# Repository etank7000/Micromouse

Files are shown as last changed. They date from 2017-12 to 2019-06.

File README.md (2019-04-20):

# Micromouse
UCLA IEEE Micromouse 2017-2018

To get the arm toolchain used in this repo, check out the following link and download the appropriate tar file. Be sure to read the included readme in the tar file as well.

https://developer.arm.com/open-source/gnu-toolchain/gnu-rm/downloads/7-2017-q4-major-1-1

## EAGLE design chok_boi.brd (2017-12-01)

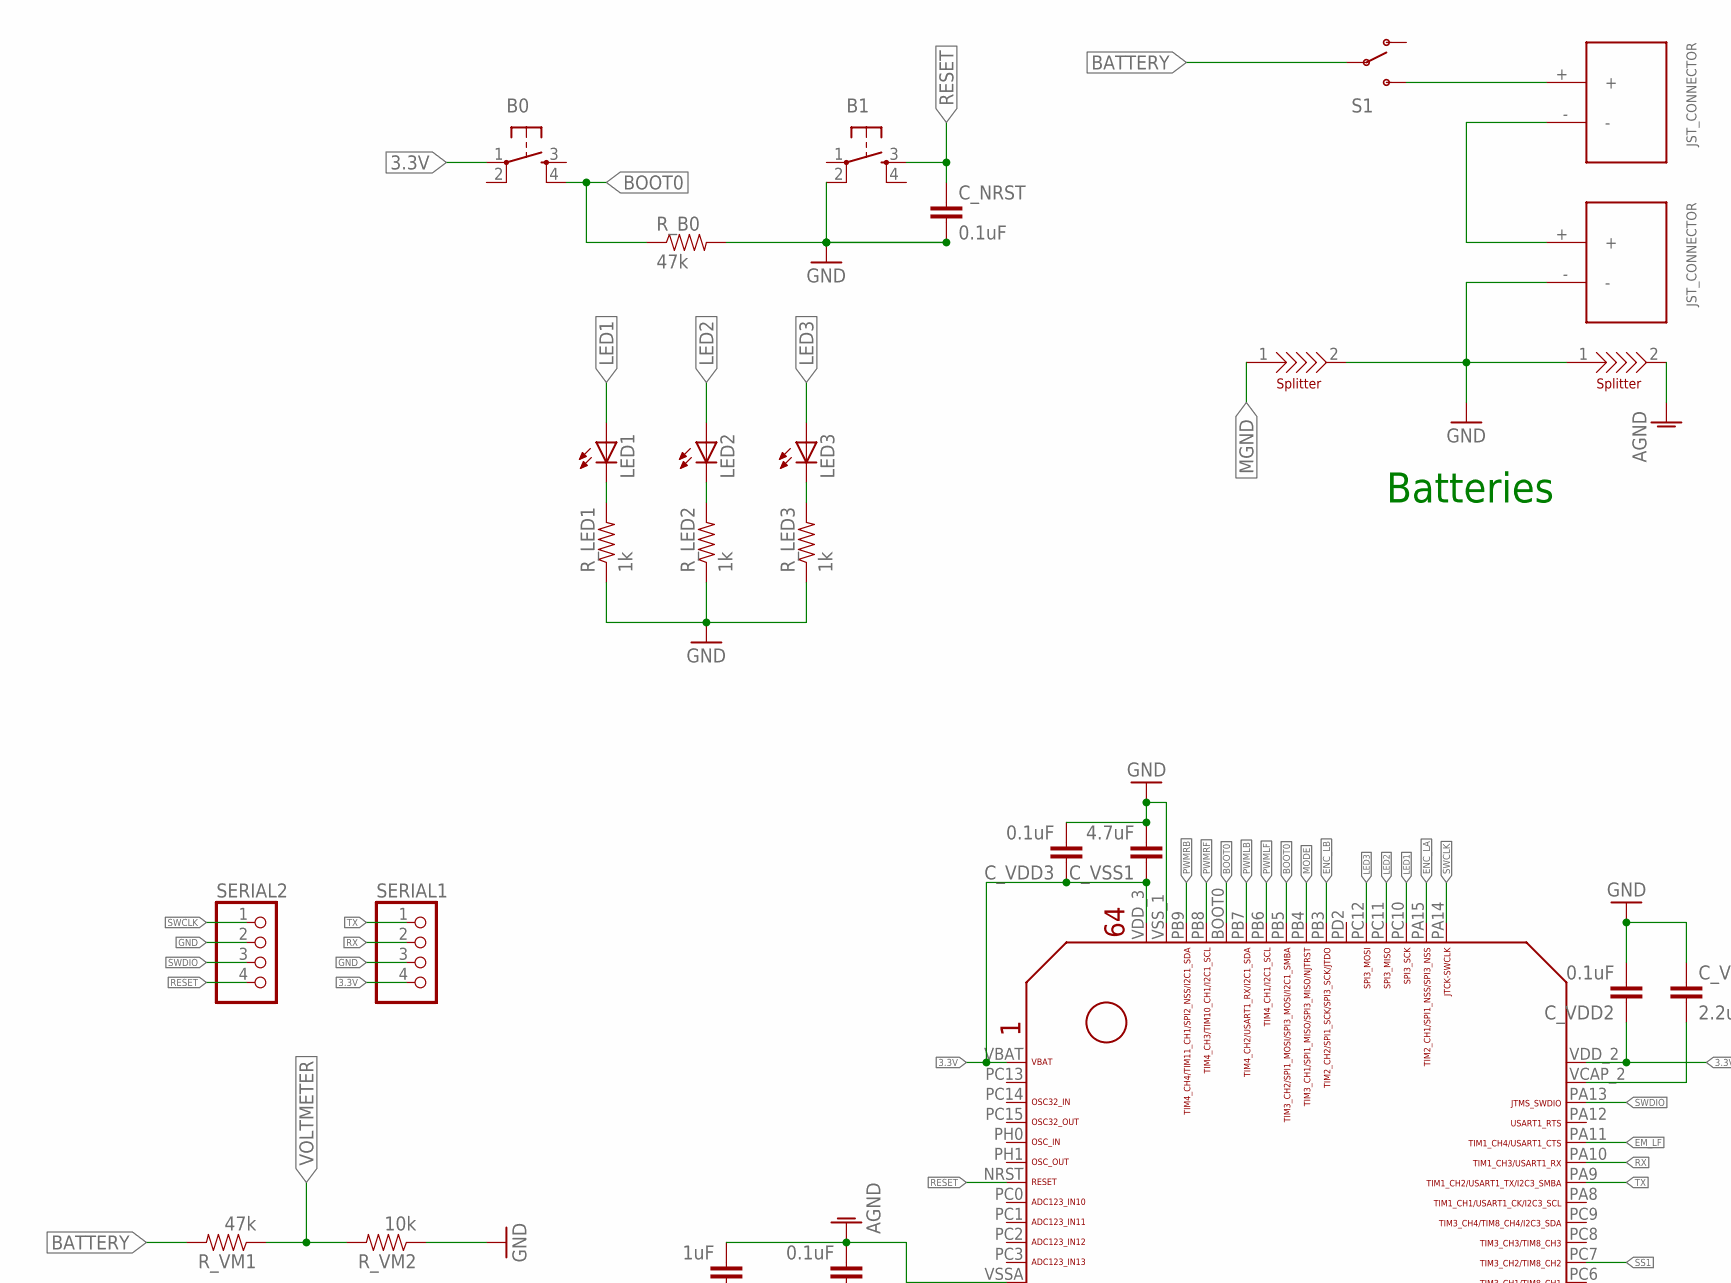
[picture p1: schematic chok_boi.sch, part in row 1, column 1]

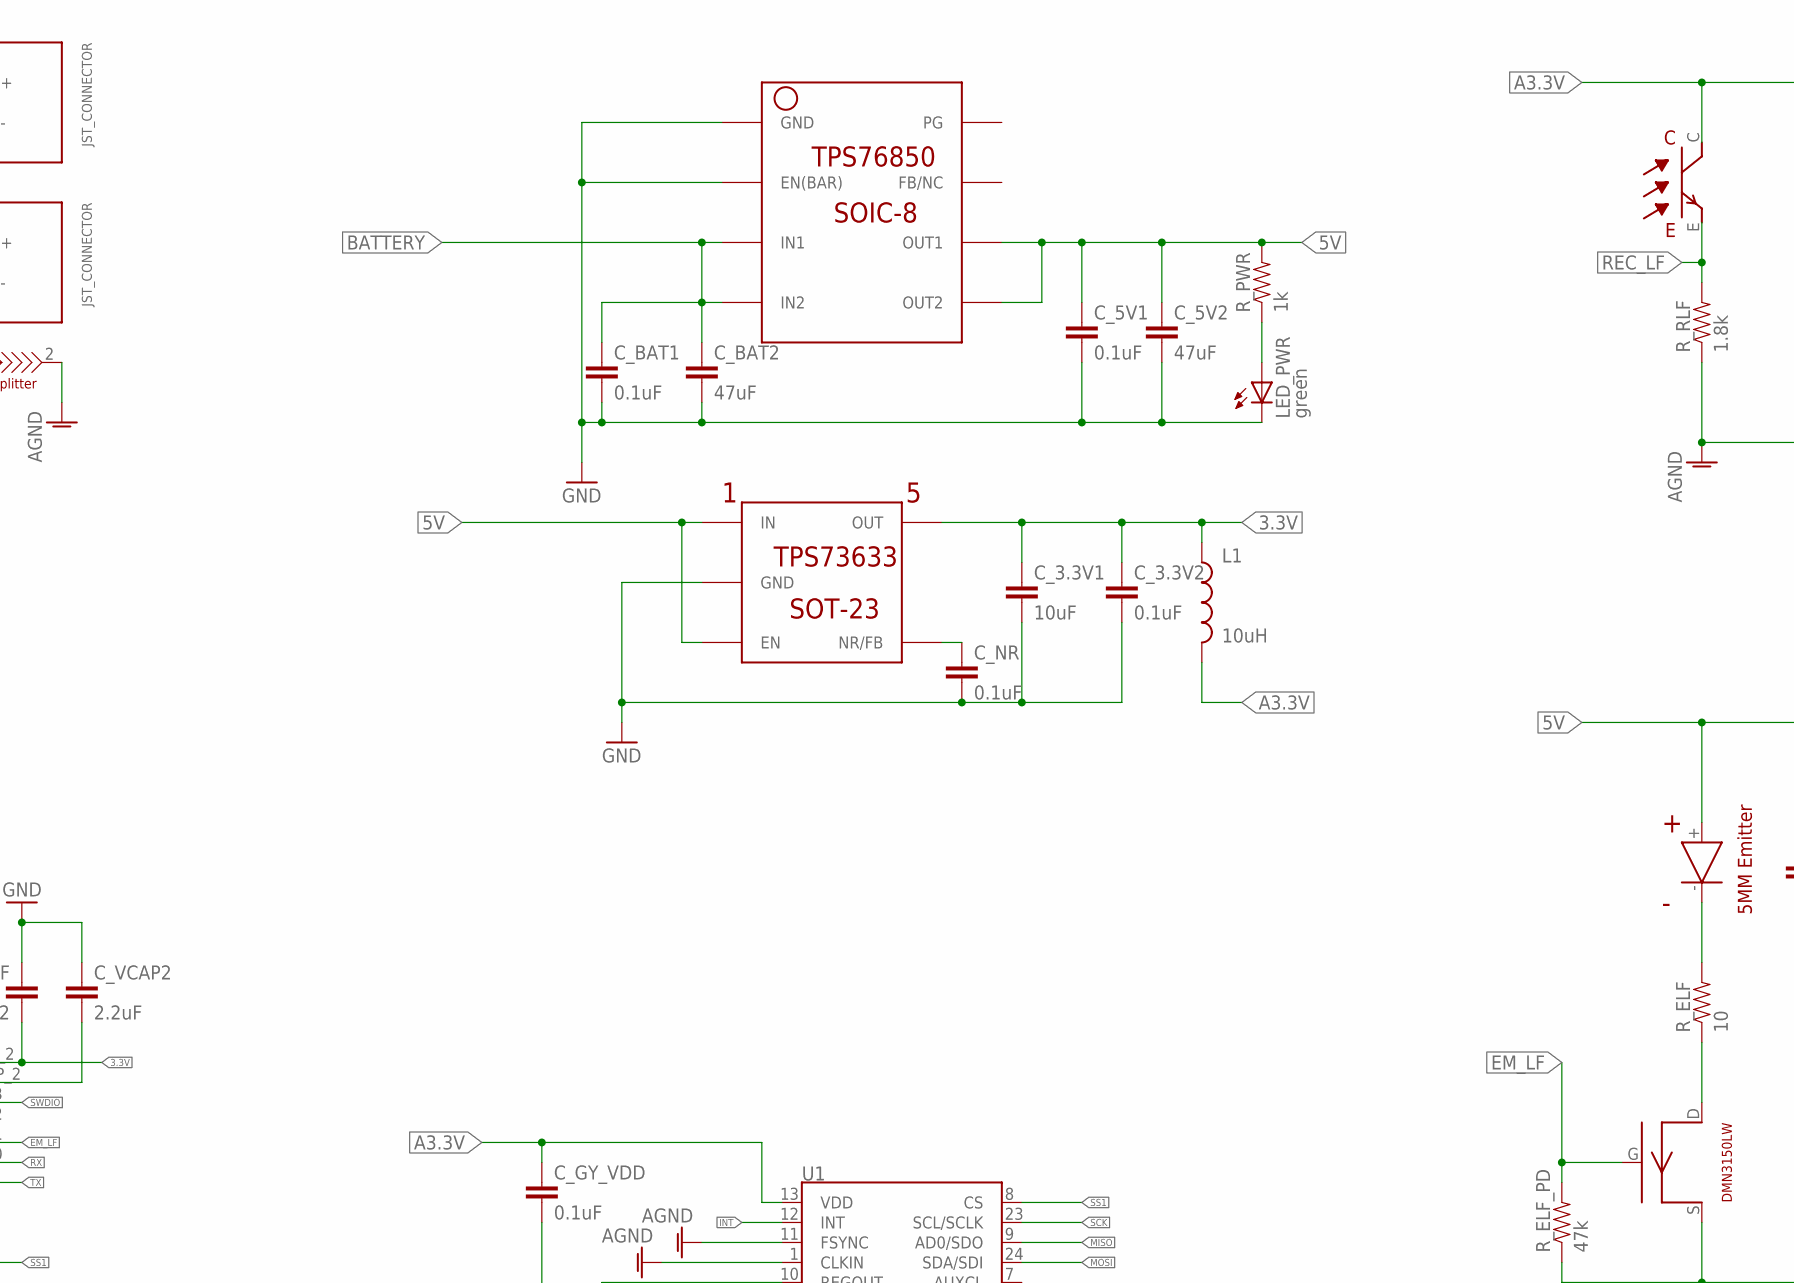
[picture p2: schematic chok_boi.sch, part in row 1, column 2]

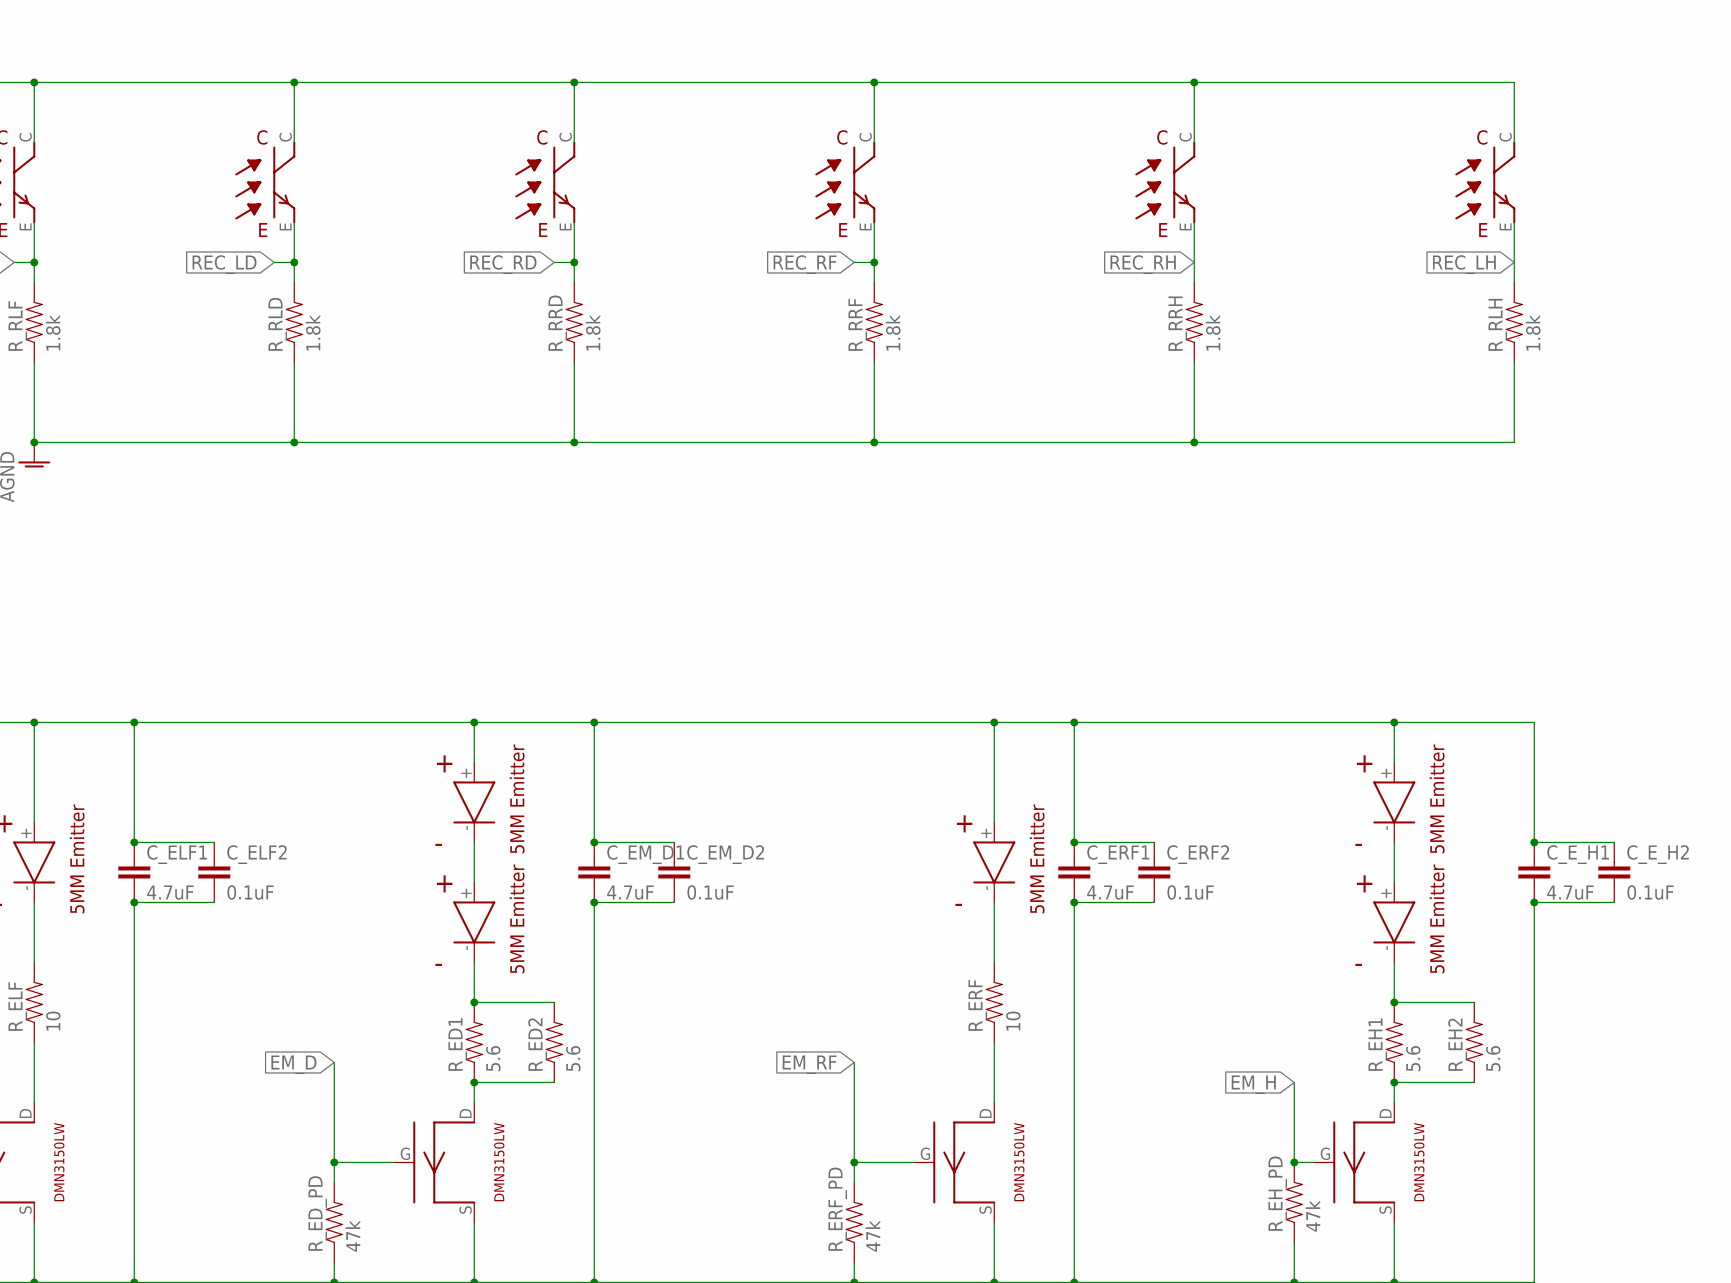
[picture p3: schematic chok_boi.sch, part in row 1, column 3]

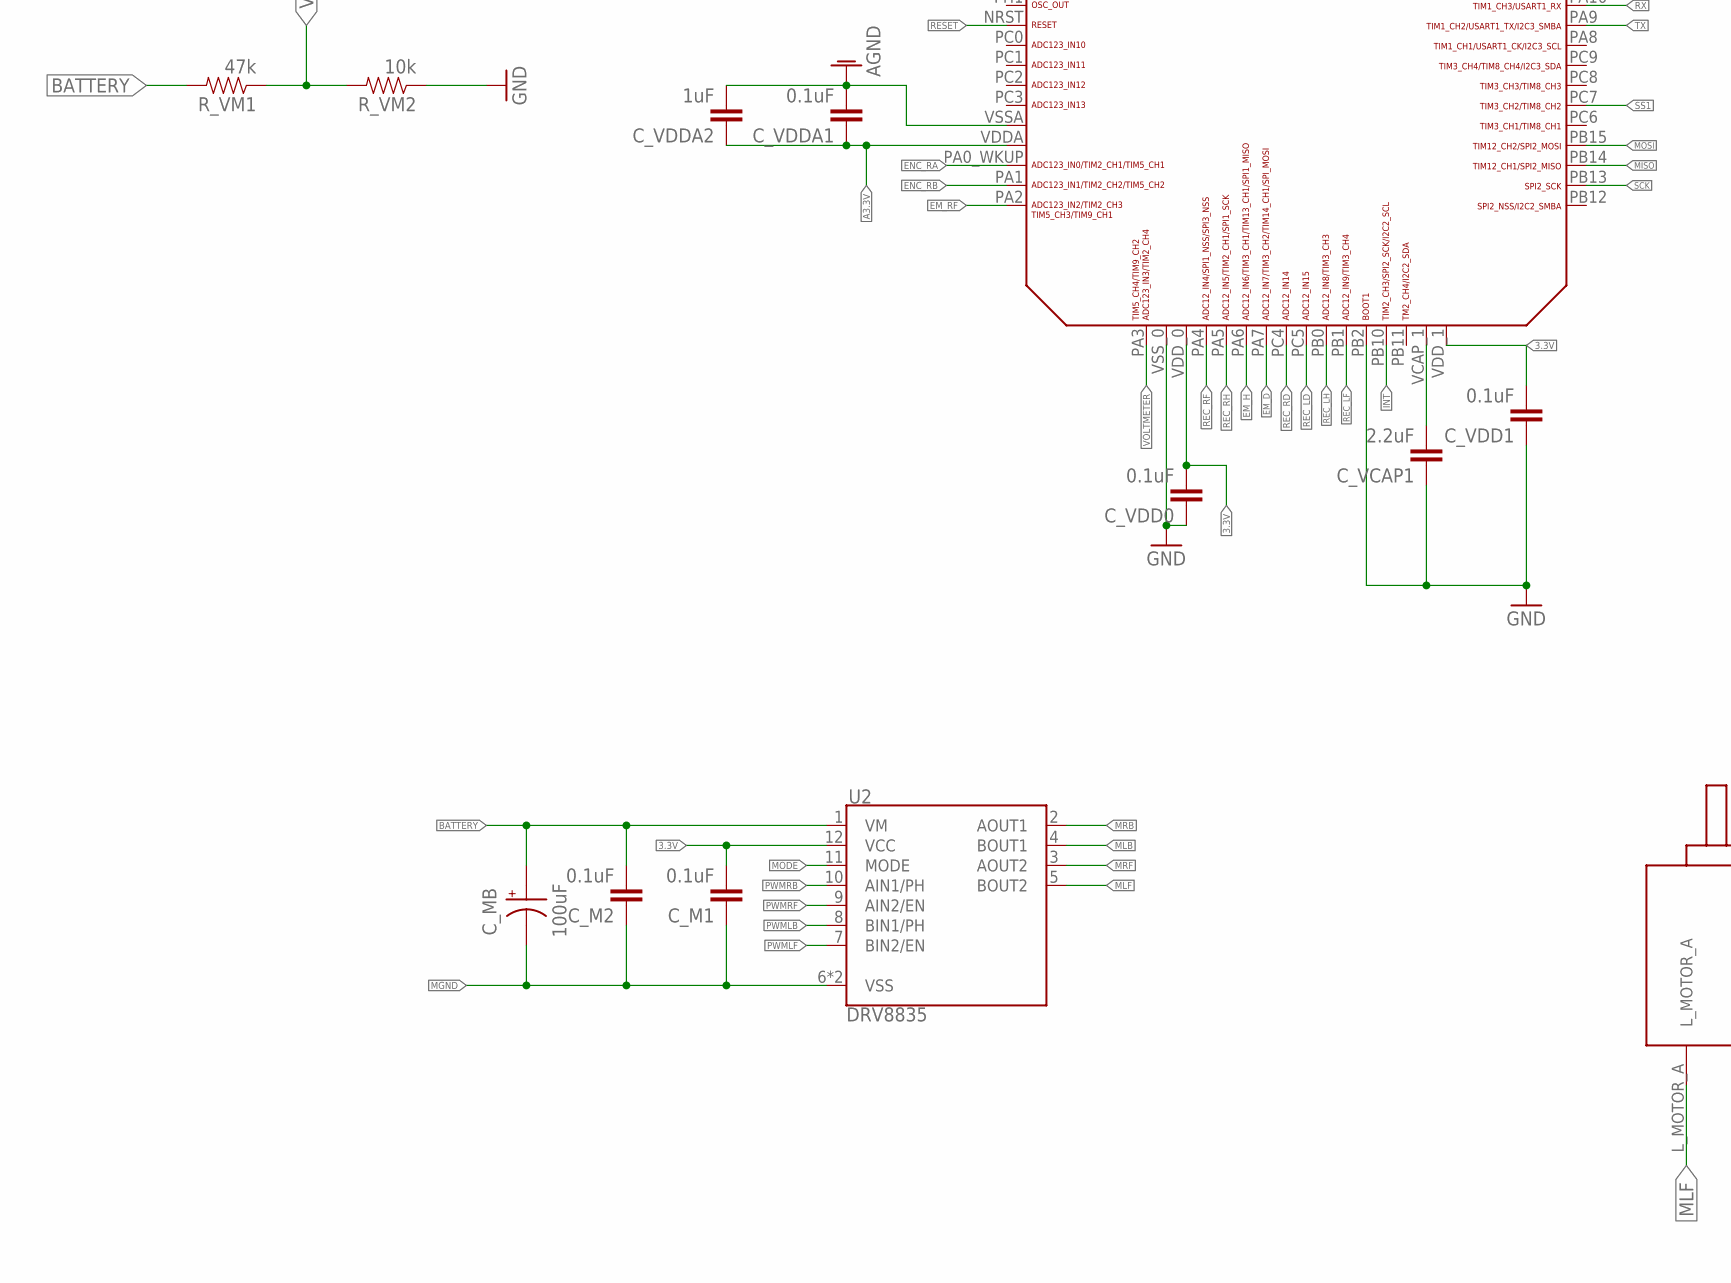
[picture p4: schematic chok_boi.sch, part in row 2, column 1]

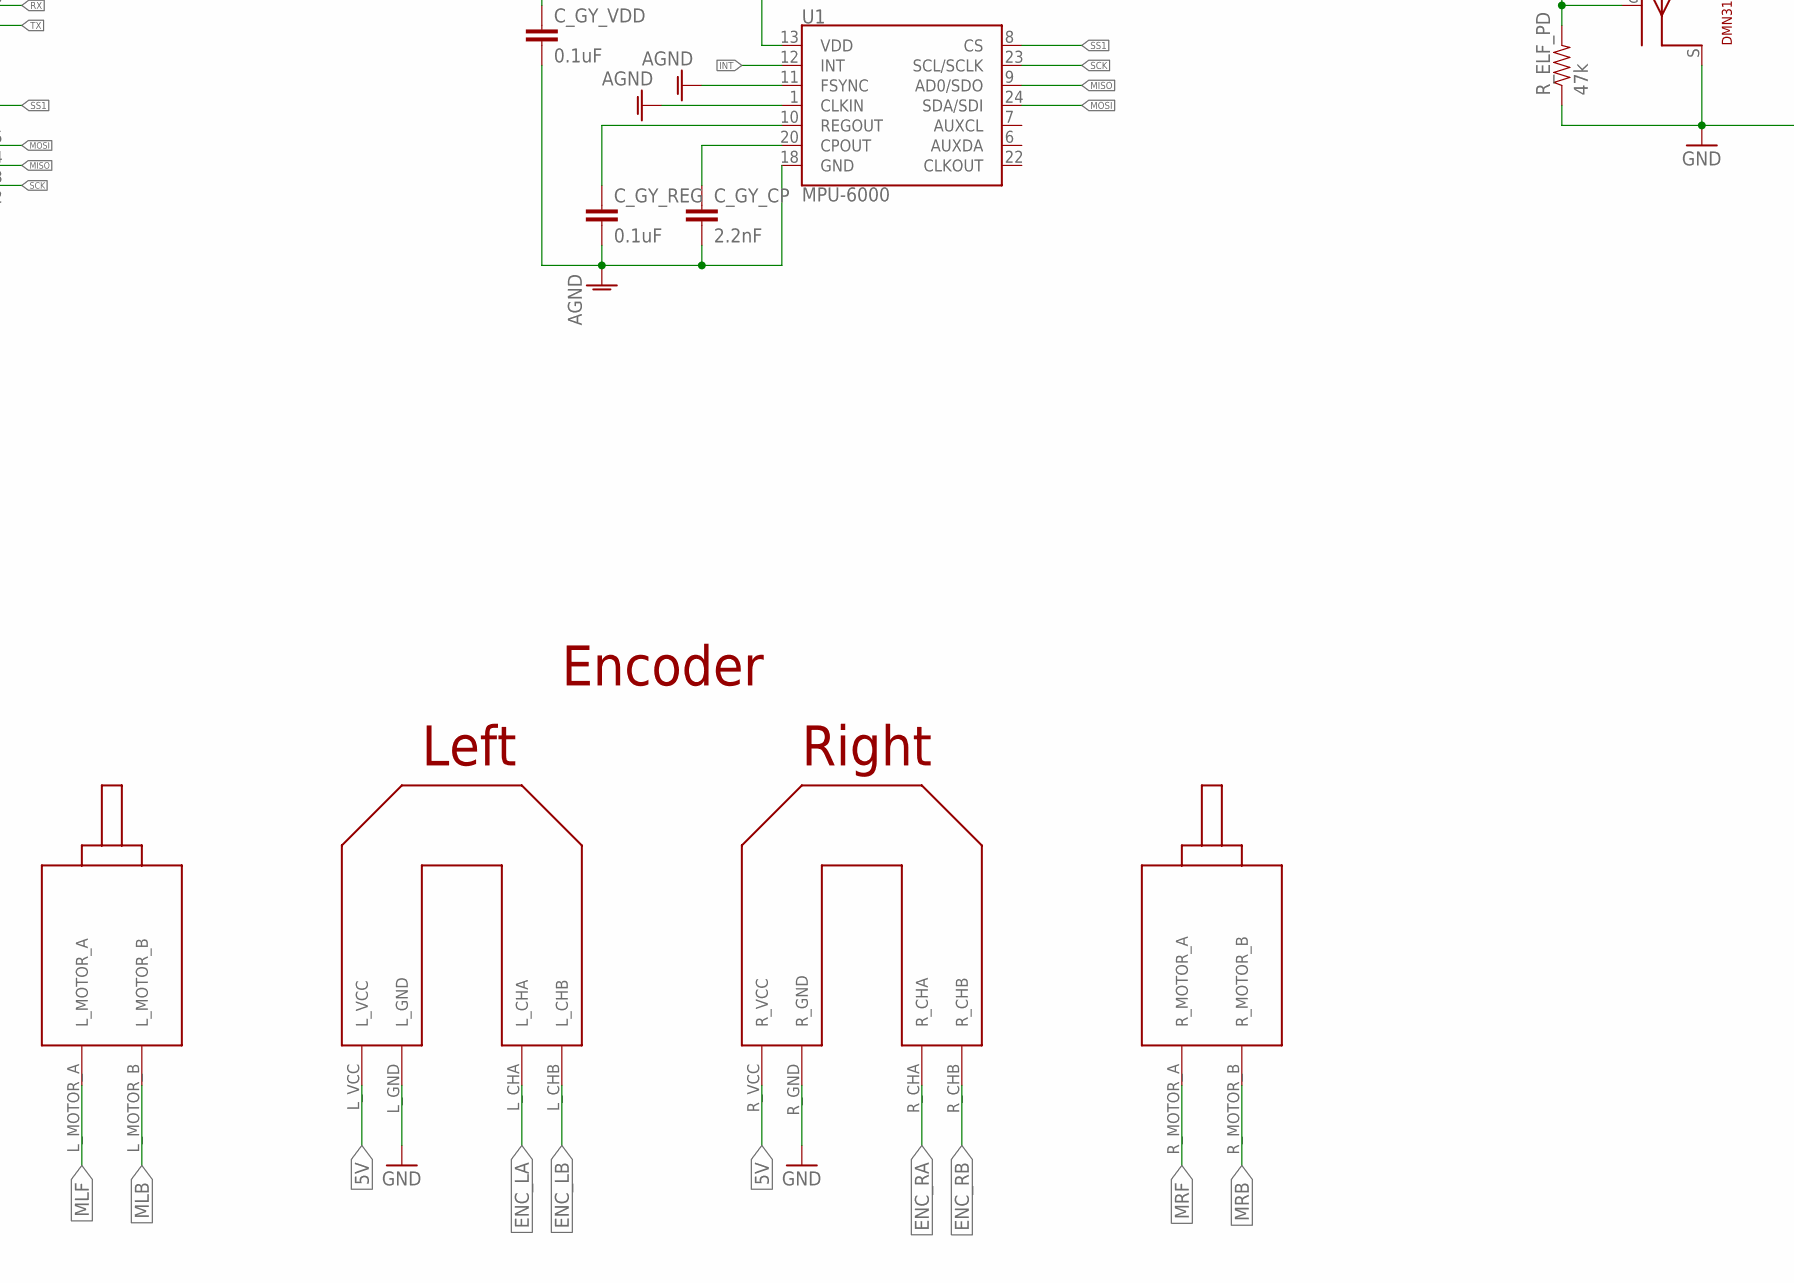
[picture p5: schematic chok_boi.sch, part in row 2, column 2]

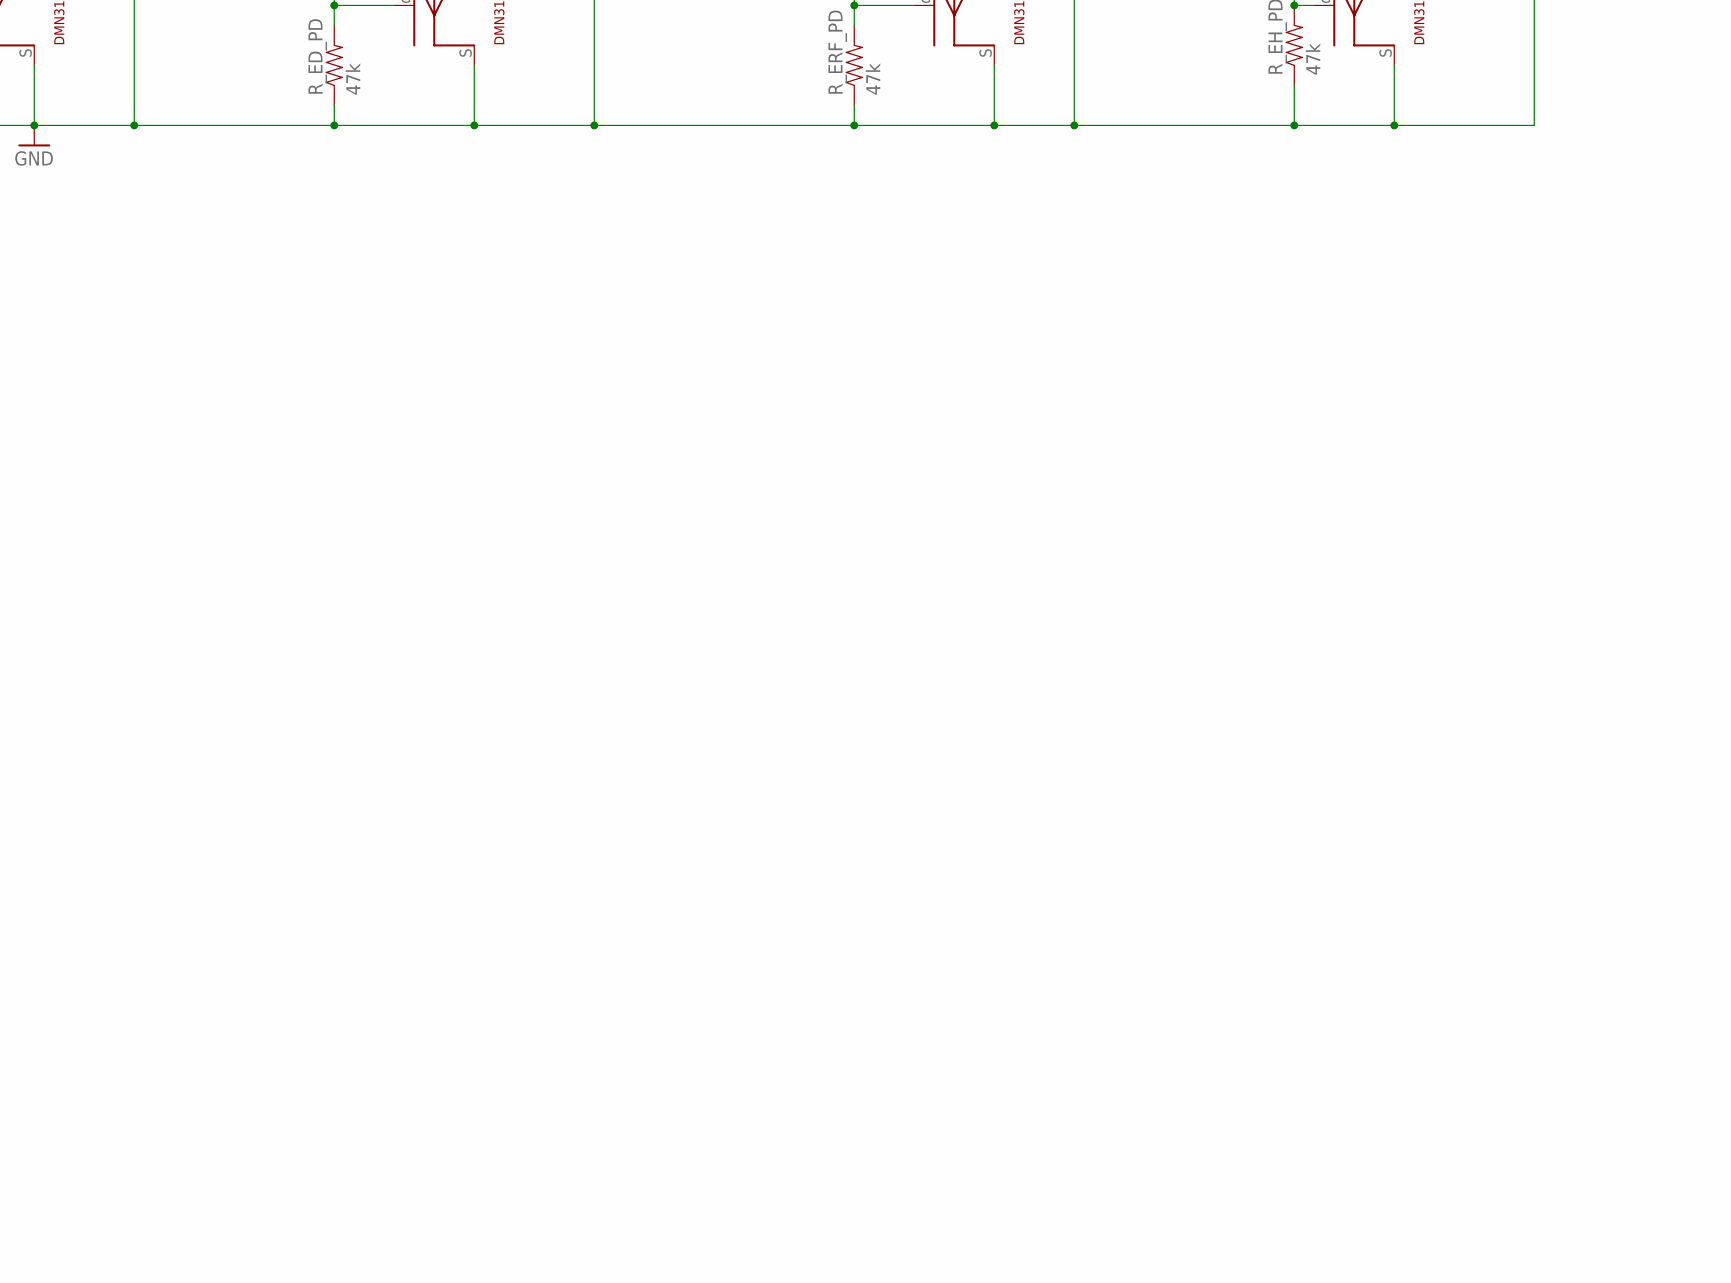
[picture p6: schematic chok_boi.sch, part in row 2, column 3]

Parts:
B0, B1: TAC_SWITCHSMD; TACTILE-SWITCH-SMD
C_3.3V1: 10uF; 0603-CAP
C_3.3V2, C_5V1: 0.1uF; 0603-CAP
C_5V2: 47uF; 1210
C_BAT1: 0.1uF; 0603-CAP
C_BAT2: 47uF; 1210
C_ELF1: 4.7uF; 0603-CAP
C_ELF2: 0.1uF; 0603-CAP
C_EM_D1: 4.7uF; 0603-CAP
C_EM_D2: 0.1uF; 0603-CAP
C_ERF1: 4.7uF; 0603-CAP
C_ERF2: 0.1uF; 0603-CAP
C_E_H1: 4.7uF; 0603-CAP
C_E_H2: 0.1uF; 0603-CAP
C_GY_CP: 2.2nF; 0603-CAP
C_GY_REG: 0.1uF; 0603-CAP
C_GY_VDD: 0.1uF; 0603-CAP
C_M1, C_M2: 0.1uF; 0603-CAP
C_MB: 100uF; X
C_NR: 0.1uF; 0603-CAP
C_NRST: 0.1uF; 0603-CAP
C_VCAP1, C_VCAP2: 2.2uF; 0603-CAP
C_VDD0, C_VDD1, C_VDD2, C_VDD3: 0.1uF; 0603-CAP
C_VDDA1: 0.1uF; 0603-CAP
C_VDDA2: 1uF; 0603-CAP
C_VSS1: 4.7uF; 0603-CAP
L1: 10uH; 1007
LED1, LED2, LED3: LED0603; LED-0603
LED_PWR: green; LED-1206
LEFT_FRONT_EMITTER: EMITTER
NMOS1, NMOS2, NMOS3, NMOS4: DMN3150LW
REC_LF: RECEIVER
R_B0: 47k; 0603-RES
R_ED1, R_ED2: 5.6; 0603-RES
R_ED_PD: 47k; 0603-RES
R_EH1, R_EH2: 5.6; 0603-RES
R_EH_PD: 47k; 0603-RES
R_ELF: 10; 0603-RES
R_ELF_PD: 47k; 0603-RES
R_ERF: 10; 0603-RES
R_ERF_PD: 47k; 0603-RES
R_LED1, R_LED2, R_LED3: 1k; 0603-RES
R_PWR: 1k; 0603-RES
R_RLD: 1.8k; 0603-RES
R_RLF: 1.8k; 0603-RES
R_RLH: 1.8k; 0603-RES
R_RRD: 1.8k; 0603-RES
R_RRF: 1.8k; 0603-RES
R_RRH: 1.8k; 0603-RES
R_VM1: 47k; 0603-RES
R_VM2: 10k; 0603-RES
S1: SWITCH-SPSTPTH; SWITCH-SPDT
SERIAL1, SERIAL2: PINHD-1X4; 1X04
U1: MPU-6000; QFN-24-EP
U2: DRV8835; WSON-12
U$1, U$2: JST_CONNECTOR_FEMALE
U$3: TPS73633(SOT-23)
U$4: TPS76850(SOIC-8)
U$5: STM32F405/415_LQFP64
U$7, U$8, U$9, U$20, U$21: RECEIVER
U$11, U$13, U$17, U$18, U$19: EMITTER
U$12: FUTURA_V1.0_MOTOR_MOUNT; FUTURA_V1.0_MOTOT_MOUNT
U$15, U$16: SPLITTER

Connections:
3.3V: B0.1, C_3.3V1.1, C_3.3V2.1, C_M1.2, C_VDD0.2, C_VDD1.2, C_VDD2.1, C_VDD3.1, C_VSS1.1, L1.1, SERIAL1.4, U2.12 (VCC), U$3.OUT, U$5.VBAT, U$5.VDD_0, U$5.VDD_1, U$5.VDD_2, U$5.VDD_3
5V: C_5V1.1, C_5V2.1, C_ELF1.1, C_ELF2.1, C_EM_D1.1, C_EM_D2.1, C_ERF1.1, C_ERF2.1, C_E_H1.1, C_E_H2.1, LEFT_FRONT_EMITTER.+, R_PWR.2, U$3.EN, U$3.IN, U$4.OUT1, U$4.OUT2, U$11.+, U$12.L_VCC, U$12.R_VCC, U$13.+, U$18.+
A3.3V: C_GY_VDD.1, C_VDDA1.1, C_VDDA2.1, L1.2, REC_LF.C, U1.13 (VDD), U$5.VDDA, U$7.C, U$8.C, U$9.C, U$20.C, U$21.C
AGND: C_GY_CP.2, C_GY_REG.2, C_GY_VDD.2, C_VDDA1.2, C_VDDA2.2, R_RLD.1, R_RLF.1, R_RLH.1, R_RRD.1, R_RRF.1, R_RRH.1, U1.1 (CLKIN), U1.11 (FSYNC), U1.18 (GND), U$5.VSSA, U$15.2
BATTERY: C_BAT1.1, C_BAT2.1, C_M2.2, C_MB.A, R_VM1.2, S1.2, U2.1 (VM), U$4.IN1, U$4.IN2
BOOT0: B0.4, R_B0.1, U$5.BOOT0, U$5.PB5
D2_EM: R_ED1.2, R_ED2.2, U$17.-
D_EM: U$11.-, U$17.+
EM_D: NMOS2.G, R_ED_PD.2, U$5.PA7
EM_H: NMOS4.G, R_EH_PD.2, U$5.PA6
EM_LF: NMOS1.G, R_ELF_PD.2, U$5.PA11
EM_RF: NMOS3.G, R_ERF_PD.2, U$5.PA2
ENC_LA: U$5.PA15, U$12.L_CHA
ENC_LB: U$5.PB3, U$12.L_CHB
ENC_RA: U$5.PA0_WKUP (PA0_AKUP), U$12.R_CHA
ENC_RB: U$5.PA1, U$12.R_CHB
GND: B1.2, C_3.3V1.2, C_3.3V2.2, C_5V1.2, C_5V2.2, C_BAT1.2, C_BAT2.2, C_ELF1.2, C_ELF2.2, C_EM_D1.2, C_EM_D2.2, C_ERF1.2, C_ERF2.2, C_E_H1.2, C_E_H2.2, C_NR.2, C_NRST.2, C_VCAP1.1, C_VCAP2.1, C_VDD0.1, C_VDD1.1, C_VDD2.2, C_VDD3.2, C_VSS1.2, LED_PWR.C, NMOS1.S, NMOS2.S, NMOS3.S, NMOS4.S, R_B0.2, R_ED_PD.1, R_EH_PD.1, R_ELF_PD.1, R_ERF_PD.1, R_LED1.1, R_LED2.1, R_LED3.1, R_VM2.1, SERIAL1.3, SERIAL2.2, U$1.-, U$3.GND, U$4.EN(BAR), U$4.GND, U$5.PB2, U$5.VSS_0, U$5.VSS_1, U$12.L_GND, U$12.R_GND, U$15.1, U$16.2
H2_EM: R_EH1.2, R_EH2.2, U$19.-
H_EM: U$18.-, U$19.+
INT: U1.12 (INT), U$5.PB10
LED1: LED1.A, U$5.PC10
LED2: LED2.A, U$5.PC11
LED3: LED3.A, U$5.PC12
LF_EM: LEFT_FRONT_EMITTER.-, R_ELF.2
MGND: C_M1.1, C_M2.1, C_MB.C, U2.6 (VSS), U2.PAD (VSS), U$16.1
MISO: U1.9 (AD0/SDO), U$5.PB14
MLB: U2.4 (BOUT1), U$12.L_MOTOR_B
MLF: U2.5 (BOUT2), U$12.L_MOTOR_A
MODE: U2.11 (MODE), U$5.PB4
MOSI: U1.24 (SDA/SDI), U$5.PB15
MRB: U2.2 (AOUT1), U$12.R_MOTOR_B
MRF: U2.3 (AOUT2), U$12.R_MOTOR_A
unnamed: U$1.+, U$2.-
unnamed: S1.3 (S), U$2.+
unnamed: C_NR.1, U$3.NR/FB
unnamed: C_VCAP1.2, U$5.VCAP_1
unnamed: NMOS3.D, R_ERF.1
unnamed: C_VCAP2.2, U$5.VCAP_2
unnamed: NMOS1.D, R_ELF.1
unnamed: LED_PWR.A, R_PWR.1
unnamed: LED1.C, R_LED1.2
unnamed: LED2.C, R_LED2.2
unnamed: NMOS2.D, R_ED1.1, R_ED2.1
unnamed: NMOS4.D, R_EH1.1, R_EH2.1
unnamed: C_GY_REG.1, U1.10 (REGOUT)
unnamed: LED3.C, R_LED3.2
unnamed: C_GY_CP.1, U1.20 (CPOUT)
PWMLB: U2.8 (BIN1/PH), U$5.PB7
PWMLF: U2.7 (BIN2/EN), U$5.PB6
PWMRB: U2.10 (AIN1/PH), U$5.PB9
PWMRF: U2.9 (AIN2/EN), U$5.PB8
REC_LD: R_RLD.2, U$5.PC5, U$7.E
REC_LF: REC_LF.E, R_RLF.2, U$5.PB1
REC_LH: R_RLH.2, U$5.PB0, U$21.E
REC_RD: R_RRD.2, U$5.PC4, U$8.E
REC_RF: R_RRF.2, U$5.PA4, U$9.E
REC_RH: R_RRH.2, U$5.PA5, U$20.E
RESET: B1.3, C_NRST.1, SERIAL2.4, U$5.NRST
RF_EM: R_ERF.2, U$13.-
RX: SERIAL1.2, U$5.PA10
SCK: U1.23 (SCL/SCLK), U$5.PB13
SS1: U1.8 (CS), U$5.PC7
SWCLK: SERIAL2.1, U$5.PA14
SWDIO: SERIAL2.3, U$5.PA13
TX: SERIAL1.1, U$5.PA9
VOLTMETER: R_VM1.1, R_VM2.2, U$5.PA3

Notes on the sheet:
Batteries

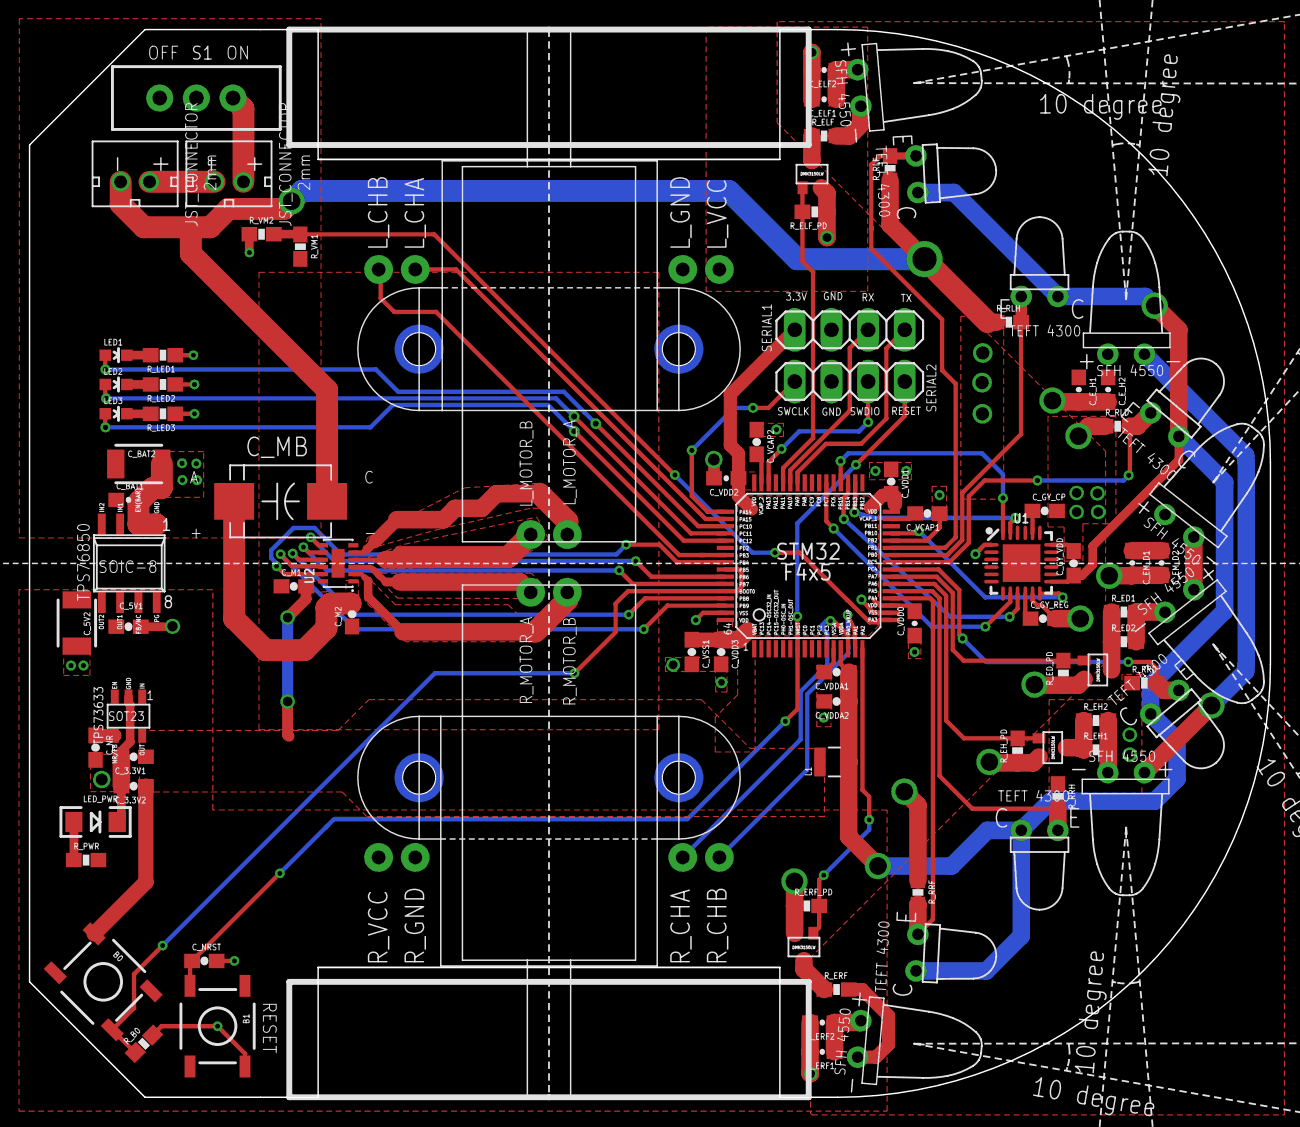
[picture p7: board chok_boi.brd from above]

Board: 2 copper layers, 86.0 x 74.0 mm, 90 parts (0 on the bottom side), 66 nets.

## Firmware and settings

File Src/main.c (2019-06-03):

/**
  ******************************************************************************
  * @file           : main.c
  * @brief          : Main program body
  ******************************************************************************
  ** This notice applies to any and all portions of this file
  * that are not between comment pairs USER CODE BEGIN and
  * USER CODE END. Other portions of this file, whether 
  * inserted by the user or by software development tools
  * are owned by their respective copyright owners.
  *
  * COPYRIGHT(c) 2018 STMicroelectronics
  *
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
  ******************************************************************************
  */
/* Includes ------------------------------------------------------------------*/
#include "main.h"
#include "stm32f4xx_hal.h"
#include "adc.h"
#include "spi.h"
#include "tim.h"
#include "usart.h"
#include "gpio.h"

/* USER CODE BEGIN Includes */
#include <limits.h>

#include "ir_sensor.h"
#include "encoder.h"
#include "controller.h"
#include "debug.h"
#include "motor.h"
#include "gyro.h"
#include "battery_checker.h"
#include "pathfinder.h"
#include "maze.h"
/* USER CODE END Includes */


/* USER CODE BEGIN PV */

static const unsigned int ENC_FLASH_RELOAD = 880UL;
static const unsigned int ENC_MODE_RELOAD = 3520UL;
static const unsigned int NUM_MODES = 8UL;
static const int REC_START = 3200;

static const float MOVE_AFTER_TURN = 0.52f;
static const float MOVE_AFTER_CURVE_TURN = 0.12f;

static const int LF_TURN = 800; // Threshold for starting curve turn
static const int RF_TURN = 800;
// OLD VALUES:
// static const int LF_TURN = 901; // Threshold for starting curve turn
// static const int RF_TURN = 1001;

static int curveTurnCounter = 0;

enum State
{
  IDLE,
  CHOOSING_FLASH, // User chooses an option for the mouse
  CHOOSING_MODE,  // User is currently choosing the mode for the mouse
  LOCKED,         // User locks in his mode choice (by pressing BOOT0 button)
  RUNNING,        // The mouse is running in one of the 8 operating modes
  CRASH
};

// Determines which mode the mouse operates in while in RUNNING State
static volatile uint32_t g_modeNum = 0;

// Determines what state the mouse is in
static volatile enum State g_state = IDLE;

// Read the flash that was written (previously stored maze runs)
static volatile uint32_t g_readWriteFlash = 0;

/* USER CODE END PV */

void SystemClock_Config(void);

/* USER CODE BEGIN PFP */

void HAL_SYSTICK_Callback(void);
void HAL_GPIO_EXTI_Callback(uint16_t GPIO_Pin);
static void chooseMode(void);

/* USER CODE END PFP */

/* USER CODE BEGIN 0 */

// This is the 1ms systick interrupt.
void HAL_SYSTICK_Callback(void)
{
  // User has locked in mode choice. Block front sensors to start running.
  if (g_state == LOCKED)
  {
    readReceivers();
    if (getRecLF() > REC_START && getRecRF() > REC_START)
    {
      g_state = IDLE;
    }
  }
  else if (g_state == RUNNING) // Systick part of mode operation
  {
    switch (g_modeNum)
    {
      // Case 0 is meant to print out values, the other cases will actually move the mouse
      // due to the call to speedProfile()
    case 0:
      readReceivers();
      updateGyroAngle();
      break;
    case 1:
    case 2:
    case 3:
    case 4:
    case 5:
    case 6:
    case 7:
      readReceivers();
      updateGyroAngle();
      speedProfile();
      break;
    }
  }
}

// This function gets called when the BOOT0 button is pressed
// or when the INT signal from the gyro is received.
void HAL_GPIO_EXTI_Callback(uint16_t GPIO_Pin)
{
  switch (GPIO_Pin)
  {
  case BOOT0_Pin:
    switch (g_state)
    {
    case CHOOSING_FLASH:
      g_state = IDLE;
      break;
    case CHOOSING_MODE:
      g_state = LOCKED;
      break;
    case LOCKED:
      // g_state = CHOOSING_MODE;
      // break;
    case RUNNING:
      g_state = CRASH;
      break;
    case IDLE:
    case CRASH:
      break;
    }
    break;
    /* case INT_Pin: */
    /*   break; */
  }
}

// Rotate the left wheel to select among 2 modes. Binary 1 indicates
// choice to read maze from flash.
static inline void chooseFlash(void)
{
  g_readWriteFlash = getLeftEnc() / (ENC_FLASH_RELOAD / 2UL);
  if (g_readWriteFlash & 1)
    set(LED3);
  else
    reset(LED3);
}

// Rotate the left wheel to select among the 8 modes. The LEDs will light
// up to correspond to the mode number. An unlit LED represents a binary 0
// while a lit LED represents a binary 1. The value is read left to right.
static inline void chooseMode(void)
{
  g_modeNum = getLeftEnc() / (ENC_MODE_RELOAD / NUM_MODES);
  if (g_modeNum & 1)
    set(LED3);
  else
    reset(LED3);
  if (g_modeNum & 2)
    set(LED2);
  else
    reset(LED2);
  if (g_modeNum & 4)
    set(LED1);
  else
    reset(LED1);
}

static inline void searchMaze(int doCurveTurn, int doExtraAdjust, int useGyro)
{
  MouseMovement nextMove = getNextMovement();

  // if (getMouseX() == 3 && getMouseY() == 2)
  //   toggle(LED2);
  // print("MouseX: %hu, MouseY: %hu \r\n", getMouseX(), getMouseY());
  switch (nextMove)
  {
  case MoveForward:
    moveForward(1.0f);
    break;
  case TurnClockwise:
    if (doCurveTurn && curveTurnCounter <= 3)
    {
      curveTurnCounter++;
      if (frontWallDetected())
      {
        toggle(LED2);
        while (getRecLF() < LF_TURN && getRecRF() < RF_TURN)
        {
        }
        // ;
      }
      else
      {
        toggle(LED1);
        // moveForward(0.19f);
        moveForward(0.20f);
      }
      turn(RightTurn, CurveTurn, useGyro);
      moveForward(MOVE_AFTER_CURVE_TURN);
      // moveForward(0.12f);
    }
    else
    {
      curveTurnCounter = 0;
      stopAtCellCenter();
      if (frontWallDetected())
      {
        adjust();
      }

      if (!doExtraAdjust)
      {
        turn(RightTurn, InPlaceTurn, useGyro);
      }
      else
      {
        if (leftWallDetected())
        {
          turn(LeftTurn, InPlaceTurn, useGyro);
          adjust();
          turnAround();
        }
        else
        {

          turn(RightTurn, InPlaceTurn, useGyro);
        }
      }

      // moveForward(0.51f);
      // moveForward(0.52f);
      moveForward(MOVE_AFTER_TURN);
    }
    break;
  case TurnCounterClockwise:
    if (doCurveTurn && curveTurnCounter <= 3)
    {
      curveTurnCounter++;
      if (frontWallDetected())
      {
        while (getRecLF() < LF_TURN && getRecRF() < RF_TURN)
        {
        }
        // ;
      }
      else
      {
        // moveForward(0.19f);
        moveForward(0.20f);
      }

      turn(LeftTurn, CurveTurn, useGyro);
      moveForward(MOVE_AFTER_CURVE_TURN);
      // moveForward(0.12f);
    }
    else
    {
      curveTurnCounter = 0;
      stopAtCellCenter();
      if (frontWallDetected())
      {
        adjust();
      }

      if (!doExtraAdjust)
      {

        turn(LeftTurn, InPlaceTurn, useGyro);
      }
      else
      {
        if (rightWallDetected())
        {

          turn(RightTurn, InPlaceTurn, useGyro);

          adjust();
          turnAround();
        }
        else
        {

          turn(LeftTurn, InPlaceTurn, useGyro);
        }
      }

      // moveForward(0.51f);
      // moveForward(0.52f);
      moveForward(MOVE_AFTER_TURN);
    }
    break;
  case TurnAround:
    stopAtCellCenter();
    if (frontWallDetected())
    {
      adjust();
    }
    if (rightWallDetected())
    {

      turn(RightTurn, InPlaceTurn, useGyro);

      adjust();

      turn(RightTurn, InPlaceTurn, useGyro);
    }
    else if (leftWallDetected())
    {

      turn(LeftTurn, InPlaceTurn, useGyro);

      adjust();

      turn(LeftTurn, InPlaceTurn, useGyro);
    }
    else
    {

      turnAround();
    }
    // moveForward(0.52f);
    // moveForward(0.51f);
    moveForward(MOVE_AFTER_TURN);
    break;
  case Wait:
    break;
  case Finish:
    stopAtCellCenter();
    g_state = IDLE;
    break;
  }
}

/* USER CODE END 0 */

/**
  * @brief  The application entry point.
  *
  * @retval None
  */
int main(void)
{
  /* MCU Configuration----------------------------------------------------------*/

  /* Reset of all peripherals, Initializes the Flash interface and the Systick. */
  HAL_Init();

  /* Configure the system clock */
  SystemClock_Config();

  /* Initialize all configured peripherals */
  MX_GPIO_Init();
  MX_ADC1_Init();
  MX_SPI2_Init();
  MX_TIM2_Init();
  MX_TIM4_Init();
  MX_TIM5_Init();
  MX_USART1_UART_Init();
  /* USER CODE BEGIN 2 */

  gyroSPIInit();
  HAL_Delay(1000);
  setGyroScale();
  HAL_Delay(1000);
  calibrateGyro();
  HAL_Delay(1000);

  HAL_TIM_Encoder_Start(&htim2, TIM_CHANNEL_ALL);
  HAL_TIM_Encoder_Start(&htim5, TIM_CHANNEL_ALL);

  // This loop is for the initial test to make sure all the sensors have
  // proper readings. Comment out or remove after verification.
  /* while (1) */
  /* { */
  /*   printSensorValues(); */
  /*   print("%d\r\n", getVoltage()); */
  /*   HAL_Delay(100); */
  /* } */

  // initializeMaze();
  // printMaze();
  // saveMazeInFlash();
  // HAL_Delay(1000);
  // readMazeFromFlash();
  // printMaze();
  // while (1) {
  //   // print("stuck in while loop\r\n");
  // }

  int firstTime = 1;
  set(MODE); // This MODE is the motor driver input
  HAL_TIM_PWM_Start(&htim4, TIM_CHANNEL_1);
  HAL_TIM_PWM_Start(&htim4, TIM_CHANNEL_3);

  while (1)
  {
    __HAL_TIM_SET_AUTORELOAD(&htim2, ENC_FLASH_RELOAD - 1UL);
    resetLeftEnc();
    resetRightEnc();
    g_state = CHOOSING_FLASH;
    // Turn left wheel to choose whether to read the maze currently saved
    // in flash memory. Binary 1 indicates read maze from flash.
    // Press BOOT0 button to lock in choice.
    while (g_state == CHOOSING_FLASH) // Exit this loop by pressing BOOT0 button.
      chooseFlash();

    if (g_readWriteFlash)
      readMazeFromFlash();

    HAL_Delay(500);

    // Change the encoder autoreload value to wrap back to 0 when it reaches
    // 3520. This is done for mode selection.
    __HAL_TIM_SET_AUTORELOAD(&htim2, ENC_MODE_RELOAD - 1UL);
    resetLeftEnc();
    resetRightEnc();

    // Use the left wheel to select a mode.
    // Turn left wheel to choose the mode. Press BOOT0 button to lock in choice.
    g_state = CHOOSING_MODE;
    while (g_state == CHOOSING_MODE) // Exit this loop by pressing BOOT0 button.
      chooseMode();

    while (g_state == LOCKED)
      ; // Block the front IR sensors to exit this loop.

    // Reaching here means we blocked the IR sensors. Prepare for running or
    // debugging by setting up the motor driver and encoder.
    int i = 0;
    float gyro_val = 0;
    uint8_t who_am_i_reg = 0;
    // All LEDs will blink 3 times to indicate that the mouse will start running.
    while (i < 6)
    {
      toggle(LED1);
      toggle(LED2);
      toggle(LED3);
      i++;
      HAL_Delay(500);
    }
    reset(LED1);
    reset(LED2);
    reset(LED3);
    __HAL_TIM_SET_AUTORELOAD(&htim2, ULONG_MAX);
    if (firstTime)
    {
      if (!g_readWriteFlash)
        initializeMaze();
      else
        initializePathFinder();
      firstTime = 0;
    }
    resetMousePosition();
    setFirstCell();
    resetLeftEnc();
    resetRightEnc();
    HAL_Delay(2);
    readReceivers();
    HAL_Delay(2);
    g_state = RUNNING;
    HAL_Delay(1);

    /* USER CODE END 2 */

    /* Infinite loop */
    /* USER CODE BEGIN WHILE */
    while (g_state == RUNNING)
    {
      /* USER CODE END WHILE */

      /* USER CODE BEGIN 3 */

      switch (g_modeNum)
      {
      case 0: // Read and print IR sensor values
        printSensorValues();
        // printAngleValues();
        break;
      case 1:
        // debugSpeedProfile();
        // moveForward(1.0);
        // stop();
        // turnAround();
        // HAL_Delay(1000);
        // moveForward(1.0);
        // HAL_Delay(100);
        // moveForward(1.0);
        // HAL_Delay(100);
        // g_state = IDLE;

        // for (int i = 0; i < 15; i++)
        // {
        //   gyro_val += readGyro();
        //   // HAL_Delay(40);
        // }

        // // who_am_i_reg = who_am_i();
        // gyro_val /= 15;
        // print("Gyro val: %d   \r\n", (int)gyro_val);
        // who_am_i();
        // HAL_Delay(100);
        // calibrateGyro();
        // HAL_Delay(100);
        // printGyroValues();
        // HAL_Delay(100);
        // turn(RightTurn, InPlaceTurn, 0);
        // HAL_Delay(100);
        // printGyroValues();
        // HAL_Delay(1000);

        // testAdjust();
        turn(RightTurn, InPlaceTurn, 1);
        HAL_Delay(730);
        break;
      case 2: // Test Turning
        turn(LeftTurn, InPlaceTurn, 1);
        HAL_Delay(730);

        // searchMaze(1, 0, 0);
        break;
      case 3:
        //   moveUntilWall();
        //   moveForward(0.55);
        //   stop();
        //   adjust();
        // turnAround();
        // HAL_Delay(730);
        searchMaze(1, 0, 0);
        break;
      case 4:
        // Run the maze with curve turns and extra adjusts
        // searchMaze(1, 1);

        // Run the maze with in place turns, no adjust, no gyro
        searchMaze(0, 0, 0);
        break;
      case 5:
        // Run the maze with curve turns but without extra adjusts
        // searchMaze(1, 0);

        // Run the maze with in place turns, no adjust, use gyro
        searchMaze(0, 0, 1);
        break;
      case 6:
        // Run the maze with in place turns and without extra adjusts
        //   searchMaze(0, 0);

        // Run the maze with in place turns, adjust, no gyro
        searchMaze(0, 1, 0);
        break;
      case 7:
        // Run the maze with in place turns and extra adjusts
        // searchMaze(0, 1);

        // Run the maze with in place turns, adjust, and gyro
        searchMaze(0, 1, 1);
        break;
      }
    }
    resetSpeedProfile();
    // Right now there is no check for whether the mouse has crashed,
    // so the maze will always be saved in flash after the mouse thinks
    // it has reached back to the start.
    if (g_state != CRASH)
    {
      saveMazeInFlash();
      HAL_Delay(100);
    }
  }

  // Reaching this point means we are done with the main routine. Proceed to
  // enter a low power state.
  while (1)
  {
    resetSpeedProfile();
    HAL_PWR_EnterSTANDBYMode();
  }
  /* USER CODE END 3 */
}

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


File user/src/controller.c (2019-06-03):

#include "controller.h"
#include "encoder.h"
#include "ir_sensor.h"
#include "motor.h"
#include "gpio.h"
#include <math.h>
#include "gyro.h"

// Conversion constants
static const int DIAMETER = 37; //35;    // Wheel diameter in millimeters
static const float PI = 3.14159265;
static const int STEPS_PER_REV = 3520; // Encoder steps per revolution
static const int CELL_WIDTH = 140;     // A cell has side length 180mm
static const int MOUSE_WIDTH = 69;     //74;  // The mouse has a width of 74mm
// Variable should be 5762 according to speed_to_counts calculation?

// TODO: Determine what this variable should be (not tested yet)
static const int CELL_ENC_COUNT = 5270; // Encoder counts per cell length
// OLD VALUE
// static const int CELL_ENC_COUNT = 5250; // Encoder counts per cell length

// Speed constants
// static const float MOVE_SPEED = 0.5; // m/s (or mm/ms)
static const float MOVE_SPEED = 0.5; // m/s (or mm/ms)
static const float MAX_SPEED = 1.0;  // m/s (or mm/ms), 1.0 is old

// Time constants
static const uint32_t PAUSE_TIME = 180; // ms
// static const uint32_t PAUSE_TIME = 228; // ms
static const uint32_t BIAS_TIME = 0;

// Acceleration constants
static const float ACC_X = 0.005; // Translational acceleration in mm/(ms)^2
static const float DEC_X = 0.005; // Translational deceleration in mm/(ms)^2
static const float ACC_W = 0.005; // Angular acceleration in mm/(ms)^2
static const float DEC_W = 0.005; // Angular deceleration in mm/(ms)^2

// Adjuster constants
static const int MOTOR_ADJUST_LIMIT = 210;
static const float ADJUST_DIVIDER = 1.01f;

// IR sensor constants
static const int SENSOR_DIVIDER = 112;

// OLD VALUES
// static const int SENSOR_DIVIDER = 90;   // increase for less correction, decrease for more correction
static const int LH_PUSH = 3320; // True mid: 2990
static const int RH_PUSH = 3320; // True mid: 2330
// OLD VALUES:
// static const int LH_PUSH = 3310; // True mid: 2990
// static const int RH_PUSH = 3315; // True mid: 2330

// // OLD VALUES
// static const int LH_PUSH = 3425; // True mid: 3303
// static const int RH_PUSH = 3240; // True mid: 3117

// LH/RH pull aren't really used anywhere
static const int LH_PULL = 2300;
static const int RH_PULL = 2300;

static const float PULL_FACTOR = 1.2f;

static const int LF_ADJUST = 3350; //3671;
static const int RF_ADJUST = 3350; //3644;

static const float ENCODER_CENTER = 0.47; // default is 0.55

// OLD VALUES
// static const int LF_ADJUST = 3433; //3671;
// static const int RF_ADJUST = 3576; //3644;
// LF: 900, RF: 1000 start to curve turn?

// Turn constants
static const float TURN_AROUND_MULTIPLIER = 1.029f;
// OLD VALUE
// static const float TURN_AROUND_MULTIPLIER = 1.025f;
static const float TURN_CONST_TIME = 0.996f;
// OLD VALUE
// static const float TURN_CONST_TIME = 0.996f;
static const float TURN_INPLACE_CONST_TIME = 0.9f;
// This value controls how much to curve turn
static const float TURN_CURVE_CONST_TIME = 0.85f;

// PID constants
static const float kpX = 2;
static const float kdX = 4;
static const float kpW = 1;
static const float kdW = 12;

// Speed variables
static float curSpeedX = 0; // Ideal current translational speed in counts/ms
static float curSpeedW = 0; // Ideal current angular speed in counts/ms
static int targetSpeedX = 0;
static int targetSpeedW = 0;

// Encoder variables
static int leftEncChange = 0;
static int rightEncChange = 0;
static volatile int encCount = 0;
static int encCountPrev = 0;
static int leftEncPrev = 0;
static int rightEncPrev = 0;

// PID variables
static float posErrorX = 0;
static float prevPosErrorX = 0;
static float posErrorW = 0;
static float prevPosErrorW = 0;

// TEST
static int firstCell = 1;
static int useSensorFeedback = 1;
static int finished = 0;
static int stop_flag = 0; // To account for initial motor bias to left
static int adjusting = 0;

// Private function prototypes
static float speed_to_counts(const float speed);
static float counts_to_speed(const float counts);
static void updateEncoderStatus(void);
static void updateCurrentSpeed(void);
static float decelerationRequired(int distanceLeft, float initialSpeed, float finalSpeed);
static int getSensorError(void);
static void calculateAdjust(void);
static void calculateMotorPwm(void);

void speedProfile(void)
{
  updateEncoderStatus();
  updateCurrentSpeed();
  if (adjusting)
  {
    calculateAdjust();
  }
  else
  {
    calculateMotorPwm();
  }
}

void resetSpeedProfile(void)
{
  reset(EM_LF);
  reset(EM_RF);
  reset(EM_H);
  reset(EM_D);
  setLeftMotor(0);
  setRightMotor(0);
  resetLeftEnc();
  resetRightEnc();

  curSpeedX = 0;
  curSpeedW = 0;
  targetSpeedX = 0;
  targetSpeedW = 0;

  leftEncChange = 0;
  rightEncChange = 0;
  encCount = 0;
  encCountPrev = 0;
  leftEncPrev = 0;
  rightEncPrev = 0;

  posErrorX = 0;
  prevPosErrorX = 0;
  posErrorW = 0;
  prevPosErrorW = 0;

  useSensorFeedback = 1;
  finished = 0;
  stop_flag = 0;
  adjusting = 0;

  reset(LED1);
  reset(LED2);
  reset(LED3);
}

void setFirstCell(void)
{
  firstCell = 1;
}

void moveUntilWall(void)
{
  encCount = 0;
  useSensorFeedback = 1;

  // Left motor bias correction
  // if (targetSpeedX == 0)
  //   stop_flag = 1;
  targetSpeedX = speed_to_counts(MOVE_SPEED);
  // if (stop_flag) {
  //   targetSpeedW = -targetSpeedX;
  //   HAL_Delay(BIAS_TIME);
  //   stop_flag = 0;
  // }
  targetSpeedW = 0;
  if (finished)
    return;
  HAL_Delay(1);
  while (!frontWallDetected())
  {
    if (encCount > CELL_ENC_COUNT)
    {
      encCount = 0;
      toggle(LED3);
    }
  }
}

// TODO: Finish/check implementation
void moveForward(float nCells)
{
  if (firstCell)
  {
    firstCell = 0;
    encCount = 0.25 * CELL_ENC_COUNT;
  }
  else
  {
    encCount = 0;
  }
  toggle(LED3);
  useSensorFeedback = 1;

  // Left motor bias correction
  // if (targetSpeedX == 0)
  //   stop_flag = 1;
  targetSpeedX = speed_to_counts(MOVE_SPEED);
  // if (stop_flag) {
  //   targetSpeedW = -1.8*targetSpeedX;
  //   HAL_Delay(BIAS_TIME);
  //   stop_flag = 0;
  // }

  targetSpeedW = 0;
  // HAL_Delay(1);
  int doneCount = nCells * CELL_ENC_COUNT;
  while (encCount < doneCount)
    ;
}
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

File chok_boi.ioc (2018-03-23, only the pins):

Mcu.UserName=STM32F405RGTx
PA0-WKUP.GPIO_Label=ENC_RA
PA0-WKUP.Signal=S_TIM5_CH1
PA1.GPIO_Label=ENC_RB
PA1.Signal=S_TIM5_CH2
PA10.Signal=USART1_RX
PA11.GPIO_Label=EM_LF
PA11.Signal=GPIO_Output
PA13.Signal=SYS_JTMS-SWDIO
PA14.Signal=SYS_JTCK-SWCLK
PA15.GPIO_Label=ENC_LA
PA15.Signal=S_TIM2_CH1_ETR
PA2.GPIO_Label=EM_RF
PA2.Signal=GPIO_Output
PA3.GPIO_Label=VOLTMETER
PA3.Signal=ADCx_IN3
PA4.GPIO_Label=REC_RF
PA4.Signal=ADCx_IN4
PA5.GPIO_Label=REC_RH
PA5.Signal=ADCx_IN5
PA6.GPIO_Label=EM_H
PA6.Signal=GPIO_Output
PA7.GPIO_Label=EM_D
PA7.Signal=GPIO_Output
PA9.Signal=USART1_TX
PB0.GPIO_Label=REC_LH
PB0.Signal=ADCx_IN8
PB1.GPIO_Label=REC_LF
PB1.Signal=ADCx_IN9
PB10.GPIO_Label=INT
PB10.Signal=GPXTI10
PB13.Signal=SPI2_SCK
PB14.Signal=SPI2_MISO
PB15.Signal=SPI2_MOSI
PB3.GPIO_Label=ENC_LB
PB3.Signal=S_TIM2_CH2
PB4.GPIO_Label=MODE
PB4.Signal=GPIO_Output
PB5.GPIO_Label=BOOT0
PB5.Signal=GPXTI5
PB6.Signal=S_TIM4_CH1
PB7.GPIO_Label=PH_L
PB7.Signal=GPIO_Output
PB8.Signal=S_TIM4_CH3
PB9.GPIO_Label=PH_R
PB9.Signal=GPIO_Output
PC10.GPIO_Label=LED1
PC10.Signal=GPIO_Output
PC11.GPIO_Label=LED2
PC11.Signal=GPIO_Output
PC12.GPIO_Label=LED3
PC12.Signal=GPIO_Output
PC4.GPIO_Label=REC_RD
PC4.Signal=ADCx_IN14
PC5.GPIO_Label=REC_LD
PC5.Signal=ADCx_IN15
PC7.GPIO_Label=SS1
PC7.Signal=GPIO_Output

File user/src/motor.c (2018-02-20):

#include "motor.h"
#include "tim.h"
#include "gpio.h"

#define PERIOD (int32_t)__HAL_TIM_GET_AUTORELOAD(&htim4)

void setLeftMotor(int32_t val)
{
  if (val > PERIOD)
  {
    val = PERIOD;
  }
  else if (val < -PERIOD)
  {
    val = -PERIOD;
  }

  if (val > 0)
  {
    reset(PH_L);
    __HAL_TIM_SET_COMPARE(&htim4, TIM_CHANNEL_1, val);
  }
  else
  {
    set(PH_L);
    __HAL_TIM_SET_COMPARE(&htim4, TIM_CHANNEL_1, -val);
  }
}

void setRightMotor(int32_t val)
{
  if (val > PERIOD)
  {
    val = PERIOD;
  }
  else if (val < -PERIOD)
  {
    val = -PERIOD;
  }

  if (val > 0)
  {
    set(PH_R);
    __HAL_TIM_SET_COMPARE(&htim4, TIM_CHANNEL_3, val);
  }
  else
  {
    reset(PH_R);
    __HAL_TIM_SET_COMPARE(&htim4, TIM_CHANNEL_3, -val);
  }
}

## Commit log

2017-11-10 add power system
    [chok_boi.sch]
2017-11-18 Add gyro and update MOSFETS
    [chok_boi.sch]
2017-11-21 Add gitignore and finish gyro connections
    [chok_boi.sch]
2017-11-21 Finish rec/led pair schematic
    [chok_boi.sch]
2017-11-22 Start board
    [chok_boi.brd]
2017-11-22 Place all big components on board
    [chok_boi.brd, chok_boi.sch]
2017-11-22 Add power and gnd planes
    [chok_boi.brd]
2017-11-22 Change part names for easier routing
    [chok_boi.brd, chok_boi.sch]
2017-11-22 Finish component placement. Start routing
    [chok_boi.brd, chok_boi.sch]
2017-11-22 117 Airwires Left
    [chok_boi.brd]
2017-11-23 Add DRV8835 motor driver
    [chok_boi.brd, chok_boi.sch]
2017-11-23 Add bypass caps to DRV8835
    [chok_boi.brd, chok_boi.sch]
2017-11-25 Add cell outline
    [chok_boi.brd]
2017-11-25 Improve upper half board placement
    [chok_boi.brd, chok_boi.sch]
2017-11-26 Modify polygons to reduce routes. 79 airwires left
    [chok_boi.brd]
2017-11-26 74 airwires left
    [chok_boi.brd]
2017-11-27 In middle of reworking traces
    [chok_boi.brd, chok_boi.sch]
2017-11-29 More routing
    [chok_boi.brd, chok_boi.sch]
2017-11-30 Move LEDs on MCU and route more. 22 airwires left
    [chok_boi.brd, chok_boi.sch]
2017-11-30 No more airwires!
    [chok_boi.brd]
2017-11-30 Move Vias further back from MCU
    [chok_boi.brd]
2017-12-01 Finish routing
    [chok_boi.brd, chok_boi.sch]
2017-12-01 Make MGND larger
    [chok_boi.brd]
2017-12-01 Design review fixes
    [chok_boi.brd]
2017-12-01 Add text to PCB and change values of 2 passives
    [chok_boi.brd, chok_boi.sch]
2017-12-16 Add code for motors, encoders, and IR sensors
2017-12-16 Move files around
    [chok_boi.brd, chok_boi.sch]
2017-12-22 Update sensor code and add stack implementation
2018-02-20 Reorganize directories and add gyro code
    [chok_boi.brd, chok_boi.sch]
2018-04-05 Start gyro changes
2018-04-20 Implement curve turn and fix diagonal IR sensors
    [controller.c, debug.c, main.c]
2018-04-30 Fix BitVector256 bug and test FloodFill
    [controller.c, main.c, maze.c]
2018-05-27 Fix flood fill bug and test for CAMM overnight build session
    [controller.c, main.c, maze.c]
2018-05-27 Working gyro code, must account for drift now!
    [debug.c, gyro.c, main.c]
2019-04-20 Start gyro work again
2019-04-27 Gyro scope working, left turn seems to be generally accurate(90degree +- 5) but right turn is bad (90 degree +- 25)
2019-05-03 Add comments and fix variable name in main.c
    [main.c]
2019-05-11 Fix curve turns and implement turns using gyros, TODO: 180s with gyro
    [controller.c, main.c, maze.c]
2019-05-26 Add turning with gyro
2019-05-26 AAMC morning of code - Remove curve turns and do with or without gyro turns

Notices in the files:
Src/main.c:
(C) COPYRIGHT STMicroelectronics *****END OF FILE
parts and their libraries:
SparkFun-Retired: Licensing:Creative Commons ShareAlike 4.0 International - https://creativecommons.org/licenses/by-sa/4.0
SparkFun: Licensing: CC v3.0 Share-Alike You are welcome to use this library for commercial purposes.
